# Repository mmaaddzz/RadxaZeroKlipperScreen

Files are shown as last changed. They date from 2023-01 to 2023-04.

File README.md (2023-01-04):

# RadxaZeroKlipperScreen
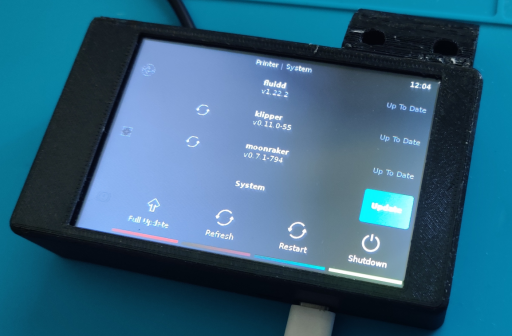
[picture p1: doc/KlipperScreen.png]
KlipperScreen


Compact Klipper based 3d-Printer control panel with 4 inch touch screen.

Radxa Zero: https://wiki.radxa.com/Zero

Lcd: http://www.lcdwiki.com/4.0inch_SPI_Module_ST7796

### Setup:

1. Armbian install
    1. A Install on MMC:
        Copy https://www.armbian.com/radxa-zero/ image into mmc card using eg https://gitlab.com/bztsrc/usbimager

    1. B Install on eMMC:
        1. Copy https://www.armbian.com/radxa-zero/ image and fallow https://wiki.radxa.com/Zero/install/eMMC instruction by:
            - Hold down the “USB BOOT” button on the Radxa Zero while connecting the USB cable
            - Run usb disk loader `sudo boot-g12.py rz-udisk-loader.bin`
            - Use eg https://gitlab.com/bztsrc/usbimager to load image into emulated Radxa Zero UDisk.
        2. Replace u-boot Armbian with Radxa u-boot (optional, may by done later):
            Armbian won't start from eMMC from time to time on my board with Armbian u-boot)
            - Fallow build procedure https://wiki.radxa.com/Zero/dev/u-boot or download u-boot image
                https://dl.radxa.com/zero/images/loader/u-boot.bin.sd.bin
            - Hold down the “USB BOOT” button on the Radxa Zero while connecting the USB cable
            - Run usb disk loader `sudo boot-g12.py rz-udisk-loader.bin`
            - Find /dev/sdX path to emulated Radxa Zero UDisk
                `sudo fdisk -l`
            - Copy u-boot into emulated Radxa Zero UDisk.
                `sudo dd if=u-boot.bin.sd.bin of=/dev/sdX bs=1 count=444`
                `sudo dd if=u-boot.bin.sd.bin of=/dev/sdX bs=512 skip=1 seek=1`

2. Setup Armbin
    - Connect serial terminal to Sys Uart
    - Power up and fallow Armbian setup

3. Install Lcd Driver
    1. Login and copy lcd_driver directory into board
    2. Build st7796 module
        - `cd lcd_driver/st7796`
        - `make && sudo make install`
        - verify module is working by
            `sudo modprobe st7796`
            `lsmod | grep st7796`
    3. Devicetree Overlay
        - `cd ../dtoverlay/`
        - `./install.sh`
        - reboot and verify lcd is working
    4. Install xorg
        - `sudo apt update && sudo apt install xserver-xorg-input-evdev`
        - `cd lcd_driver/xorg.conf.d/`
        - `sudo cp 99-calibration.conf /usr/share/X11/xorg.conf.d`
        - `sudo cp 99-fbturbo.conf /usr/share/X11/xorg.conf.d`
        - `sudo cp /usr/share/X11/xorg.conf.d/10-evdev.conf /usr/share/X11/xorg.conf.d/45-evdev.conf # fix for touch issue`

4. Use https://github.com/th33xitus/kiauh to install Klipper and KlipperScrean
    - check /dev/fbX device, see: https://klipperscreen.readthedocs.io/en/latest/Troubleshooting/#screen-shows-console-instead-of-klipperscreen
    - Aux Uart is /dev/ttyAML6

TODO:
    1. check spi errors: st7796 spi0.0: SPI transfer timed out
    2. improve cleanup kernel module
    3. use DKMS to moudule auto rebuild
    4. add freecad 3d models

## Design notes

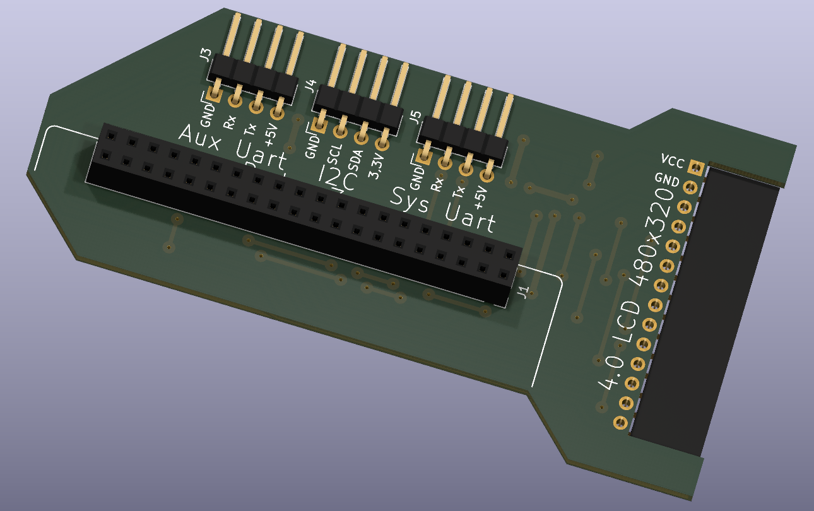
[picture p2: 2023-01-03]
doc/Pcb_3D_View.png

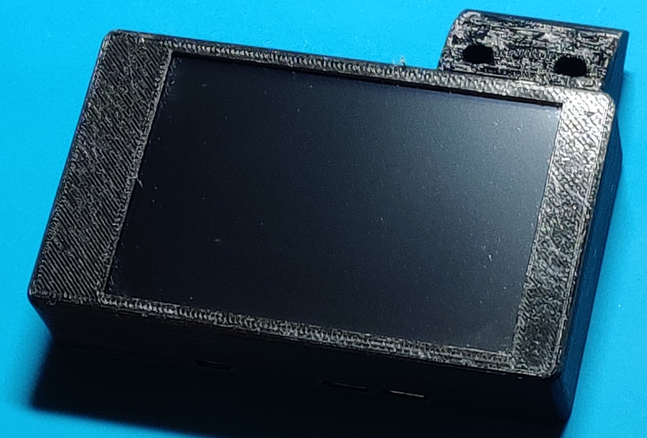
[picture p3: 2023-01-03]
doc/Controler_Front.png

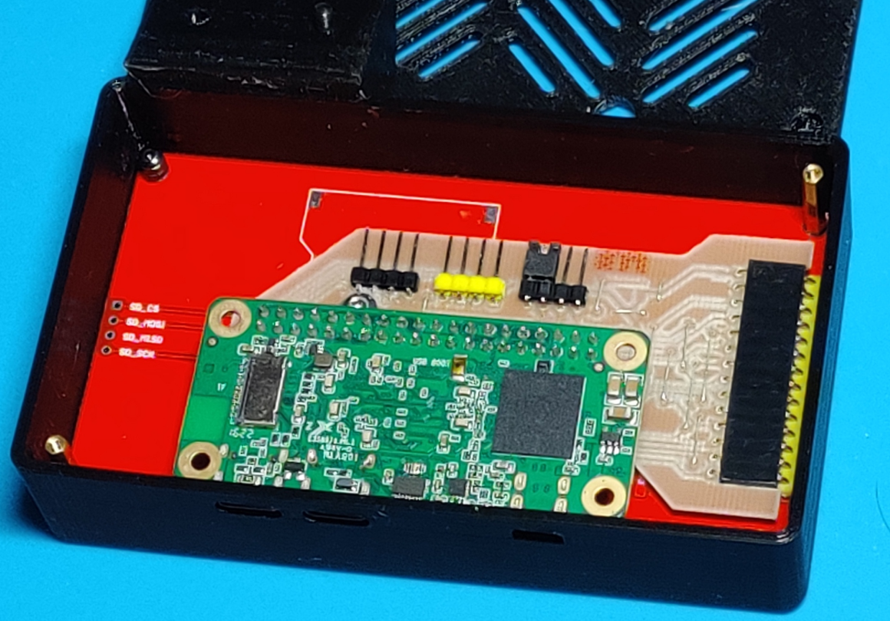
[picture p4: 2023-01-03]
doc/Controler_Back.png

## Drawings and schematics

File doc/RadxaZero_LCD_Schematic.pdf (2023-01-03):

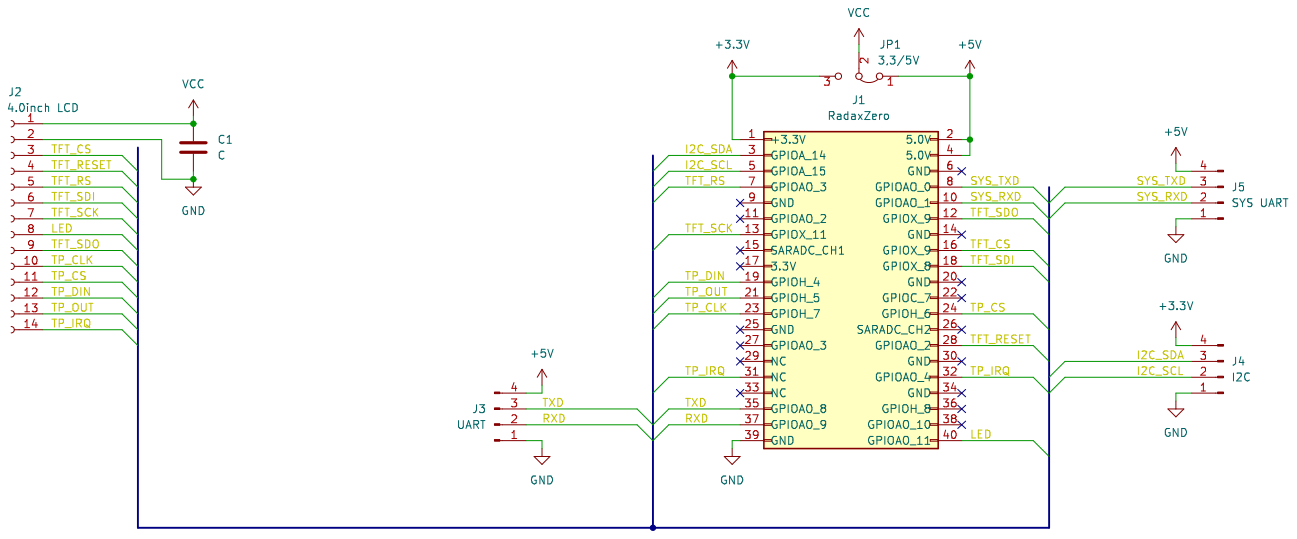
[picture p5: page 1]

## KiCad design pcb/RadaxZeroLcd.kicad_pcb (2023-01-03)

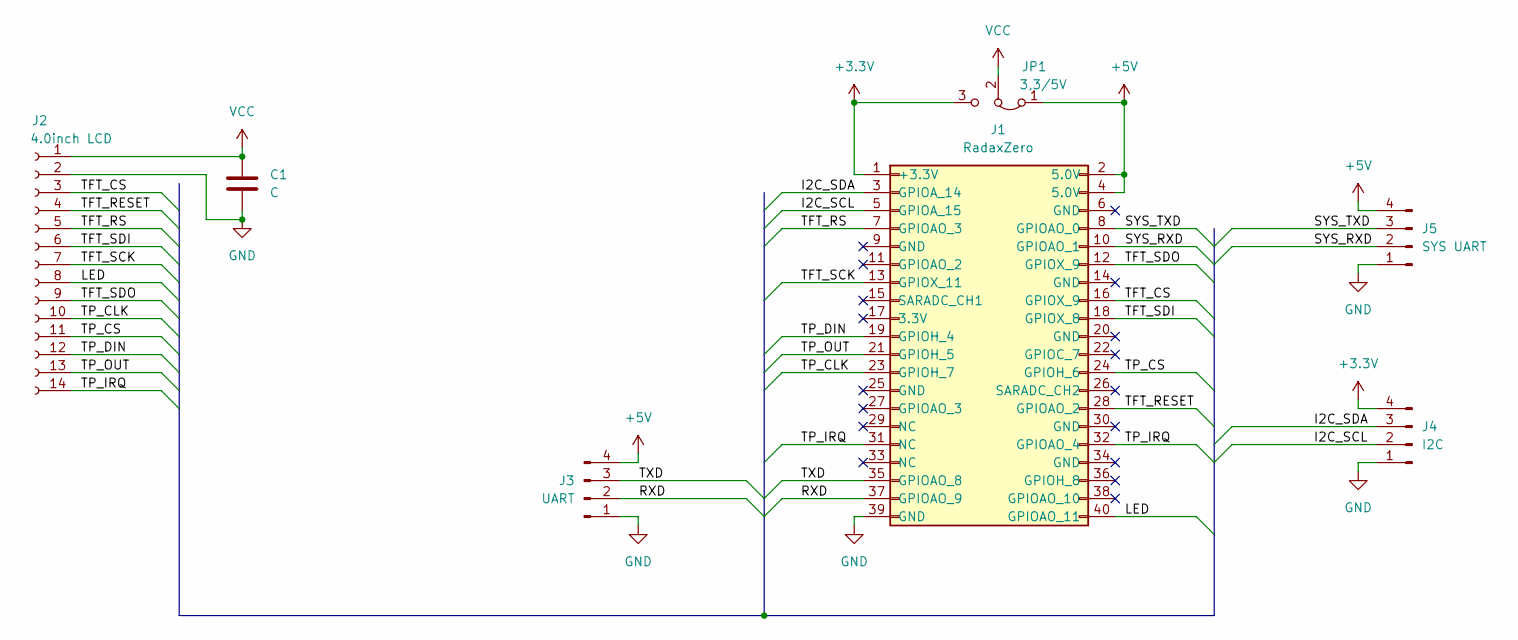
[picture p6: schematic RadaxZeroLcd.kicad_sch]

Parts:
C1: C; C_0805_2012Metric
J1: RadaxZero; PinSocket_2x20_P2.54mm_Vertical
J2: 4.0inch LCD; PinSocket_1x14_P2.54mm_Horizontal
J3: UART; PinHeader_1x04_P2.54mm_Horizontal
J4: I2C; PinHeader_1x04_P2.54mm_Horizontal
J5: SYS UART; PinHeader_1x04_P2.54mm_Horizontal
JP1: 3,3/5V; SolderJumper-3_P1.3mm_Open_RoundedPad1.0x1.5mm

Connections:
+3.3V: J1.1 (+3.3V), J4.4, JP1.3 (B)
+5V: J1.2 (5.0V), J1.4 (5.0V), J3.4, J5.4, JP1.1 (A)
/I2C_SCL: J1.5 (GPIOA_15), J4.2
/I2C_SDA: J1.3 (GPIOA_14), J4.3
/LED: J1.40 (GPIOAO_11), J2.8
/RXD: J1.37 (GPIOAO_9), J3.2
/SYS_RXD: J1.10 (GPIOAO_1), J5.2
/SYS_TXD: J1.8 (GPIOAO_0), J5.3
/TFT_CS: J1.16 (GPIOX_9), J2.3
/TFT_RESET: J1.28 (GPIOAO_2), J2.4
/TFT_RS: J1.7 (GPIOAO_3), J2.5
/TFT_SCK: J1.13 (GPIOX_11), J2.7
/TFT_SDI: J1.18 (GPIOX_8), J2.6
/TFT_SDO: J1.12 (GPIOX_9), J2.9
/TP_CLK: J1.23 (GPIOH_7), J2.10
/TP_CS: J1.24 (GPIOH_6), J2.11
/TP_DIN: J1.19 (GPIOH_4), J2.12
/TP_IRQ: J1.31 (NC), J1.32 (GPIOAO_4), J2.14
/TP_OUT: J1.21 (GPIOH_5), J2.13
/TXD: J1.35 (GPIOAO_8), J3.3
GND: C1.2, J1.39 (GND), J2.2, J3.1, J4.1, J5.1
VCC: C1.1, J2.1, JP1.2 (C)

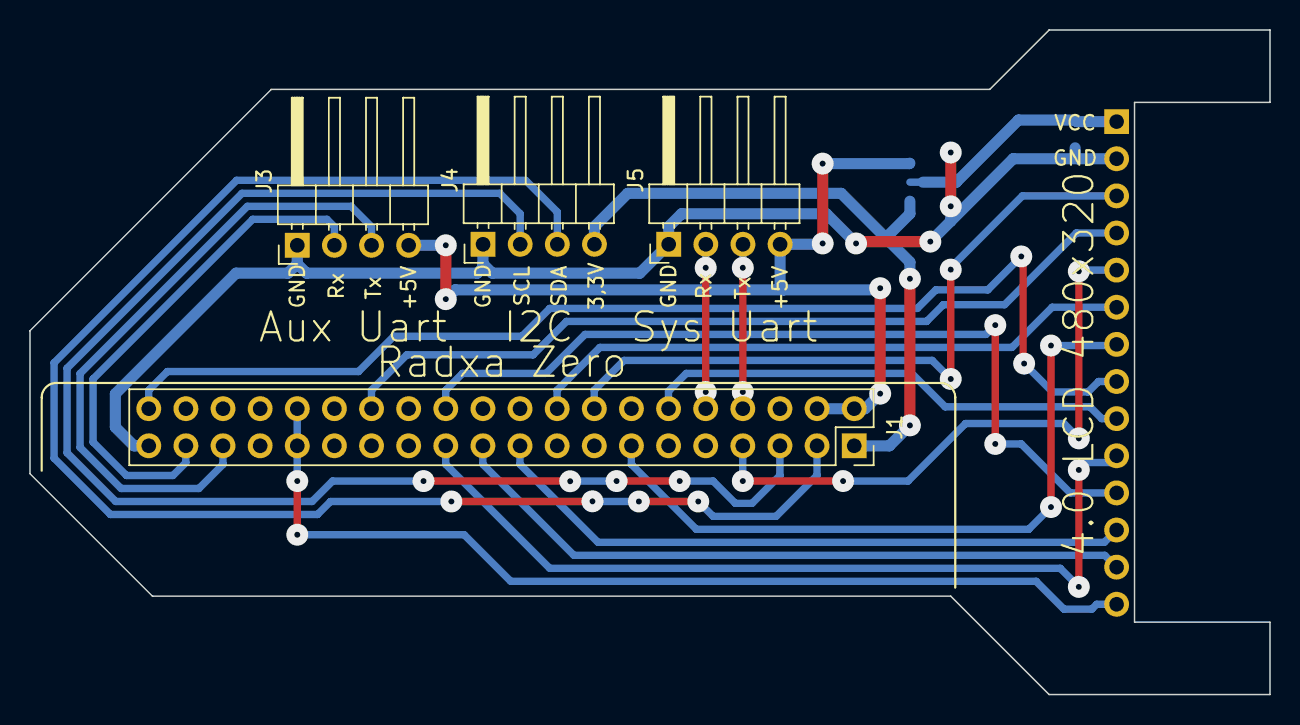
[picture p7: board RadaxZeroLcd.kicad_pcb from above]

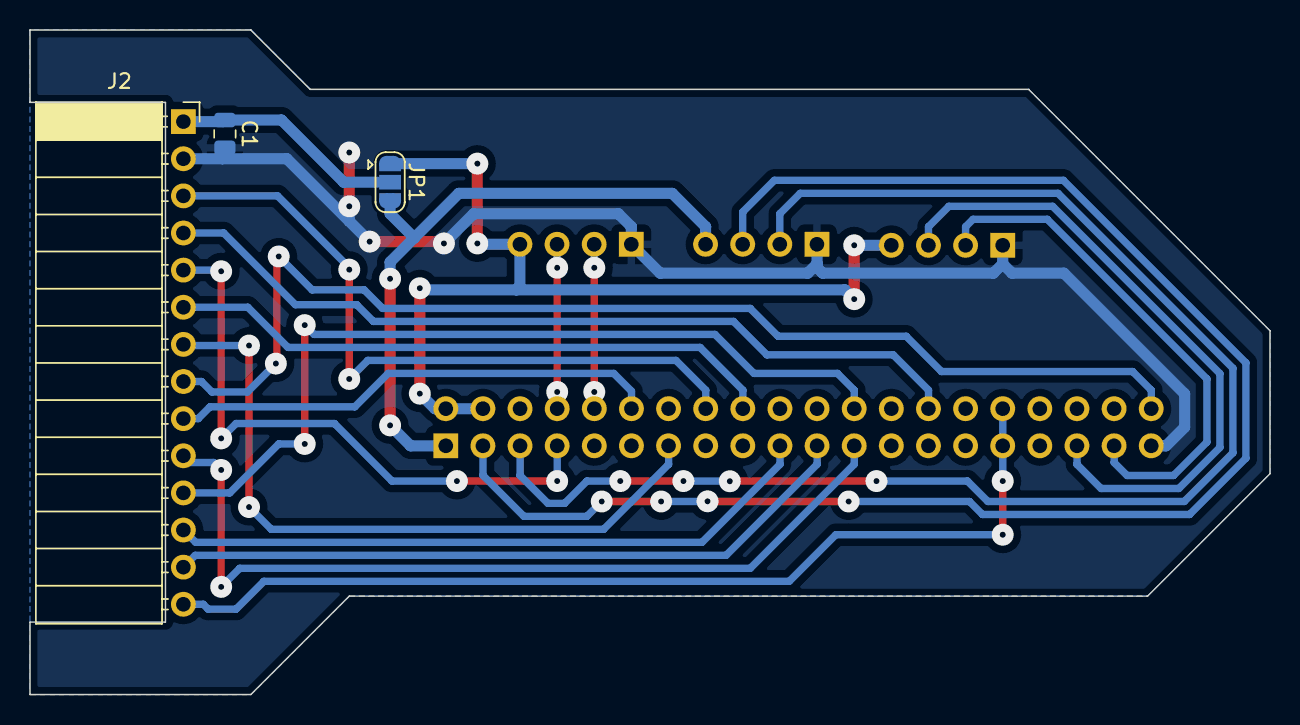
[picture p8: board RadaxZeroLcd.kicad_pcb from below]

Board: 2 copper layers, 84.8 x 45.5 mm, 7 parts (3 on the bottom side), 22 nets.

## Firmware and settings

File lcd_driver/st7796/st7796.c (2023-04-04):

// SPDX-License-Identifier: GPL-2.0+
/*
 * DRM driver for display panels connected to a Sitronix ST7715R or ST7735R
 * display controller in SPI mode.
 *
 * Copyright 2017 David Lechner <david@lechnology.com>
 * Copyright (C) 2019 Glider bvba
 * Modified for ST7796 display driver
 */

#include <linux/backlight.h>
#include <linux/delay.h>
#include <linux/dma-buf.h>
#include <linux/gpio/consumer.h>
#include <linux/module.h>
#include <linux/property.h>
#include <linux/spi/spi.h>
#include <video/mipi_display.h>

#include <drm/drm_atomic_helper.h>
#include <drm/drm_drv.h>
#include <drm/drm_fb_helper.h>
#if __has_include (<drm/drm_fbdev_generic.h>)
 #include <drm/drm_fbdev_generic.h>
#endif
#include <drm/drm_gem_atomic_helper.h>
#if __has_include (<drm/drm_gem_dma_helper.h>)
 #include <drm/drm_gem_dma_helper.h>
#else
 #include <drm/drm_gem_cma_helper.h>
 #define DEFINE_DRM_GEM_DMA_FOPS     DEFINE_DRM_GEM_CMA_FOPS
 #define DRM_GEM_DMA_DRIVER_OPS_VMAP DRM_GEM_CMA_DRIVER_OPS_VMAP
#endif
#include <drm/drm_gem_framebuffer_helper.h>
#include <drm/drm_managed.h>
#include <drm/drm_mipi_dbi.h>

// #define ST7735R_FRMCTR1		0xb1
// #define ST7735R_FRMCTR2		0xb2
// #define ST7735R_FRMCTR3		0xb3
// #define ST7735R_INVCTR		0xb4
// #define ST7735R_PWCTR1		0xc0
// #define ST7735R_PWCTR2		0xc1
// #define ST7735R_PWCTR3		0xc2
// #define ST7735R_PWCTR4		0xc3
// #define ST7735R_PWCTR5		0xc4
// #define ST7735R_VMCTR1		0xc5
// #define ST7735R_GAMCTRP1	0xe0
// #define ST7735R_GAMCTRN1	0xe1

#define ST7796_MY	BIT(7)
#define ST7796_MX	BIT(6)
#define ST7796_MV	BIT(5)
#define ST7796_RGB	BIT(3)

#define ST7796_CSCON		0xF0






struct st7796_cfg {
	const struct drm_display_mode mode;
	unsigned int left_offset;
	unsigned int top_offset;
	unsigned int write_only:1;
	unsigned int rgb:1;		/* RGB (vs. BGR) */
};

struct st7796_priv {
	struct mipi_dbi_dev dbidev;	/* Must be first for .release() */
	const struct st7796_cfg *cfg;
};

static void st7796_pipe_enable(struct drm_simple_display_pipe *pipe,
				struct drm_crtc_state *crtc_state,
				struct drm_plane_state *plane_state)
{
	struct mipi_dbi_dev *dbidev = drm_to_mipi_dbi_dev(pipe->crtc.dev);
	struct st7796_priv *priv = container_of(dbidev, struct st7796_priv,
						 dbidev);
	struct mipi_dbi *dbi = &dbidev->dbi;
	int ret, idx;
	u8 addr_mode;

	if (!drm_dev_enter(pipe->crtc.dev, &idx))
		return;

	DRM_DEBUG_KMS("\n");

	ret = mipi_dbi_poweron_reset(dbidev);
	if (ret)
		goto out_exit;

	msleep(150);

	mipi_dbi_command(dbi, MIPI_DCS_EXIT_SLEEP_MODE);
	msleep(500);

	mipi_dbi_command(dbi, ST7796_CSCON, 0xC3);
    mipi_dbi_command(dbi, ST7796_CSCON, 0x96);
//    mipi_dbi_command(dbi, MIPI_DCS_SET_ADDRESS_MODE, 0x68);
    mipi_dbi_command(dbi, MIPI_DCS_SET_PIXEL_FORMAT, MIPI_DCS_PIXEL_FMT_16BIT);
    mipi_dbi_command(dbi, 0xB0, 0x80);
    mipi_dbi_command(dbi, 0xB6, 0x00, 0x02);
    mipi_dbi_command(dbi, 0xB5, 0x02, 0x03, 0x00, 0x04);
    mipi_dbi_command(dbi, 0xB1, 0x80, 0x10);
    mipi_dbi_command(dbi, 0xB4, 0x00);
    mipi_dbi_command(dbi, 0xB7, 0xC6);
    mipi_dbi_command(dbi, 0xC5, 0x24);
    mipi_dbi_command(dbi, 0xE4, 0x31);
    mipi_dbi_command(dbi, 0xE8, 0x40, 0x8A, 0x00, 0x00, 0x29, 0x19, 0xA5, 0x33, 0xC2, 0xA7);
    mipi_dbi_command(dbi, 0xE0, 0xF0, 0x09, 0x13, 0x12, 0x12, 0x2B, 0x3C, 0x44, 0x4B, 0x1B, 0x18, 0x17, 0x1D, 0x21);
    mipi_dbi_command(dbi, 0xE1, 0xF0, 0x09, 0x13, 0x0C, 0x0D, 0x27, 0x3B, 0x44, 0x4D, 0x0B, 0x17, 0x17, 0x1D, 0x21);
//    mipi_dbi_command(dbi, MIPI_DCS_SET_ADDRESS_MODE, 0xEC);
    mipi_dbi_command(dbi, 0xF0, 0xC3);
    mipi_dbi_command(dbi, 0xF0, 0x69);
    mipi_dbi_command(dbi, MIPI_DCS_ENTER_NORMAL_MODE);
    mipi_dbi_command(dbi, MIPI_DCS_EXIT_SLEEP_MODE);
//    mipi_dbi_command(dbi, MIPI_DCS_SET_DISPLAY_ON);

//	mipi_dbi_command(dbi, ST7735R_FRMCTR1, 0x01, 0x2c, 0x2d);
//	mipi_dbi_command(dbi, ST7735R_FRMCTR2, 0x01, 0x2c, 0x2d);
//	mipi_dbi_command(dbi, ST7735R_FRMCTR3, 0x01, 0x2c, 0x2d, 0x01, 0x2c,
//			 0x2d);
//	mipi_dbi_command(dbi, ST7735R_INVCTR, 0x07);
//	mipi_dbi_command(dbi, ST7735R_PWCTR1, 0xa2, 0x02, 0x84);
//	mipi_dbi_command(dbi, ST7735R_PWCTR2, 0xc5);
//	mipi_dbi_command(dbi, ST7735R_PWCTR3, 0x0a, 0x00);
//	mipi_dbi_command(dbi, ST7735R_PWCTR4, 0x8a, 0x2a);
//	mipi_dbi_command(dbi, ST7735R_PWCTR5, 0x8a, 0xee);
//	mipi_dbi_command(dbi, ST7735R_VMCTR1, 0x0e);
//	mipi_dbi_command(dbi, MIPI_DCS_EXIT_INVERT_MODE);
	switch (dbidev->rotation) {
	default:
		addr_mode = ST7796_MX;
		break;
	case 90:
		addr_mode = ST7796_MV;
		break;
	case 180:
		addr_mode = ST7796_MY;
		break;
	case 270:
		addr_mode = ST7796_MX | ST7796_MY | ST7796_MV;
		break;
	}

	//if (priv->cfg->rgb)
		addr_mode |= ST7796_RGB;

	mipi_dbi_command(dbi, MIPI_DCS_SET_ADDRESS_MODE, addr_mode);
//	mipi_dbi_command(dbi, MIPI_DCS_SET_PIXEL_FORMAT,
//			 MIPI_DCS_PIXEL_FMT_16BIT);
//	mipi_dbi_command(dbi, ST7735R_GAMCTRP1, 0x02, 0x1c, 0x07, 0x12, 0x37,
//			 0x32, 0x29, 0x2d, 0x29, 0x25, 0x2b, 0x39, 0x00, 0x01,
//			 0x03, 0x10);
//	mipi_dbi_command(dbi, ST7735R_GAMCTRN1, 0x03, 0x1d, 0x07, 0x06, 0x2e,
//			 0x2c, 0x29, 0x2d, 0x2e, 0x2e, 0x37, 0x3f, 0x00, 0x00,
//			 0x02, 0x10);
	mipi_dbi_command(dbi, MIPI_DCS_SET_DISPLAY_ON);

	msleep(100);

	mipi_dbi_command(dbi, MIPI_DCS_ENTER_NORMAL_MODE);

	msleep(20);

	mipi_dbi_enable_flush(dbidev, crtc_state, plane_state);
out_exit:
	drm_dev_exit(idx);
}

static const struct drm_simple_display_pipe_funcs st7796_pipe_funcs = {
	.enable		= st7796_pipe_enable,
	.disable	= mipi_dbi_pipe_disable,
	.update		= mipi_dbi_pipe_update,
};

static const struct st7796_cfg qd40037c1_00_cfg = {
	.mode		= { DRM_SIMPLE_MODE(320, 480, 56, 84) },
	.write_only	= true,
};

DEFINE_DRM_GEM_DMA_FOPS(st7796_fops);

static struct drm_driver st7796_driver = {
	.driver_features	= DRIVER_GEM | DRIVER_MODESET | DRIVER_ATOMIC,
	.fops			= &st7796_fops,
	DRM_GEM_DMA_DRIVER_OPS_VMAP,
	.debugfs_init		= mipi_dbi_debugfs_init,
	.name			= "st7796",
	.desc			= "Sitronix ST7796",
	.date			= "20220630",
	.major			= 1,
	.minor			= 0,
};

static const struct of_device_id st7796_of_match[] = {
	{ .compatible = "quandong,qd40037c1-00", .data = &qd40037c1_00_cfg },
	{ },
};
MODULE_DEVICE_TABLE(of, st7796_of_match);

static const struct spi_device_id st7796_id[] = {
	{ "qd40037c1-00", (uintptr_t)&qd40037c1_00_cfg },
	{ },
};
MODULE_DEVICE_TABLE(spi, st7796_id);
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

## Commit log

2023-01-03 pcb project upload
    [RadaxZeroLcd.kicad_pcb, RadaxZeroLcd.kicad_sch]
2023-01-03 update radxa zero footprint
    [RadaxZeroLcd.kicad_pcb, RadaxZeroLcd.kicad_sch]
2023-01-04 Module driver, Kernel DTO and setup instruction
2023-04-04 fix compilation issues on kernel v6.2.0
    [st7796.c]
